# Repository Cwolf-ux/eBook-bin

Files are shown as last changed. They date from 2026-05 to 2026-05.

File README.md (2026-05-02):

# eBook-bin
这是一个基于esp32的电子书可以用来阅读小说和察看天气目前我还没有添加太多功能后续我还打算给它加上连接蓝牙耳机听音乐的功能（也许吧）
总之目前可以使用就对了（因为我是高中生所以可能没什么时间更新代码请见谅）B站：Cwolf
时钟芯片使用DS1302
屏幕的话使用的时1.54寸的黑白双色屏 如果你的屏幕是arduino中的GxEPD2_54_T8驱动也可以直接使用，24p的接口
购买链接
【闲鱼】https://m.tb.cn/h.iEBmmNw?tk=L2Xv5OOD1jG CA381 「快来捡漏【全新1.54寸 WFT0154CZ17 黑白墨水屏】」
#小程序://闲鱼/UHppd5wqVrUnHnr
点击链接直接打开

5e49f3b043350d6cdf3bbe58eff1679a
1a4ab55a5c0fa75fe380342cb2c60797
3bd9f81abdd300e44c9b036ef0b76970
18b52c07360b9da5afa7ad33fd001fbd
电路板就暂时不开源了如有需要请联系我，请各位谅解！！！

接线
========================================
 ESP32 电子书硬件接线图 (依据代码引脚)
========================================

一、墨水屏 (GxEPD2_154_T8)
--------------------------------------
ESP32引脚    墨水屏引脚
GPIO5   ->   CS
GPIO21  ->   DC
GPIO15  ->   RST
GPIO16  ->   BUSY
GPIO18  ->   SCK  (SPI时钟)
GPIO23  ->   MOSI (SPI数据输出)
3.3V    ->   VCC
GND     ->   GND

二、SD卡模块 (SPI模式)
--------------------------------------
ESP32引脚    SD卡模块引脚
GPIO4   ->   CS
GPIO18  ->   SCK   (与墨水屏共用)
GPIO19  ->   MISO
GPIO23  ->   MOSI  (与墨水屏共用)
3.3V    ->   VCC
GND     ->   GND

三、DS1302 实时时钟
--------------------------------------
ESP32引脚    DS1302引脚
GPIO14  ->   DAT (I/O)
GPIO27  ->   CLK (SCLK)
GPIO12  ->   RST (CE)
3.3V    ->   VCC
GND     ->   GND

四、按钮 (内部上拉，按下为低电平)
--------------------------------------
左键: GPIO26 --[按键]-- GND
中键: GPIO32 --[按键]-- GND
右键: GPIO33 --[按键]-- GND

五、LED背光
--------------------------------------
GPIO25 --[220欧电阻]-- LED阳极 -- LED阴极 -- GND

六、电池电压测量 (两电阻分压)
--------------------------------------
电池正极 (+)
   │
   ├── 10kΩ电阻 ──┬── GPIO35 (ADC)
   │               │
   └── 电池负极 ── 10kΩ电阻 ── GND

说明：两个10kΩ电阻串联，中点接GPIO35。
满电4.2V时，ADC引脚电压为2.1V，安全。

七、电源连接
--------------------------------------
所有模块的VCC接ESP32的3.3V输出。
所有GND共地。
电池通过分压电路测量，ESP32主供电建议使用稳定3.3V电源。

========================================
        注意事项
========================================
1. SPI总线(18/19/23)为ESP32默认VSPI，墨水屏与SD卡仅CS不同。
2. 按钮使用内部上拉(INPUT_PULLUP)，外部无需上拉电阻。
3. 电池分压电阻已固定，软件已做校准。
4. GPIO35仅能做输入，适合ADC测量。
5. 如开发板引脚定义不同，请根据实际型号调整。

========================================
制作：Cwolf-Cc
版本：1.0
========================================

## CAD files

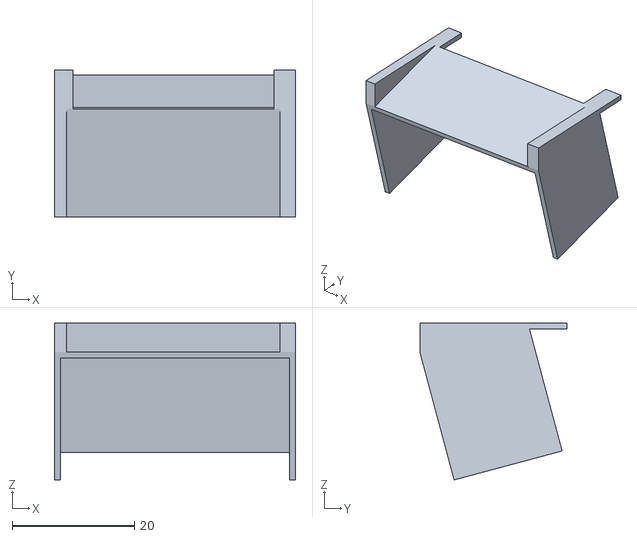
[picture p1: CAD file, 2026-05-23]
3d模型 3dmode/电子书二代支架.stl
39.5 x 24.2 x 25.7

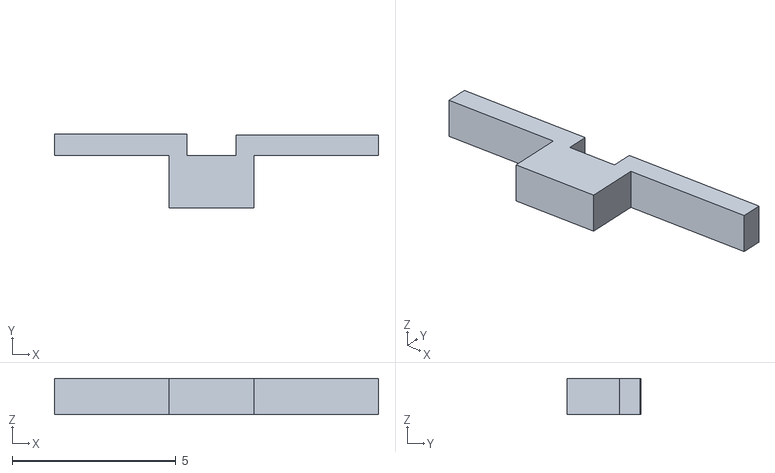
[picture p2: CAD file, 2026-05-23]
3d模型 3dmode/电子书二代开关.stl
9.90 x 2.26 x 1.10

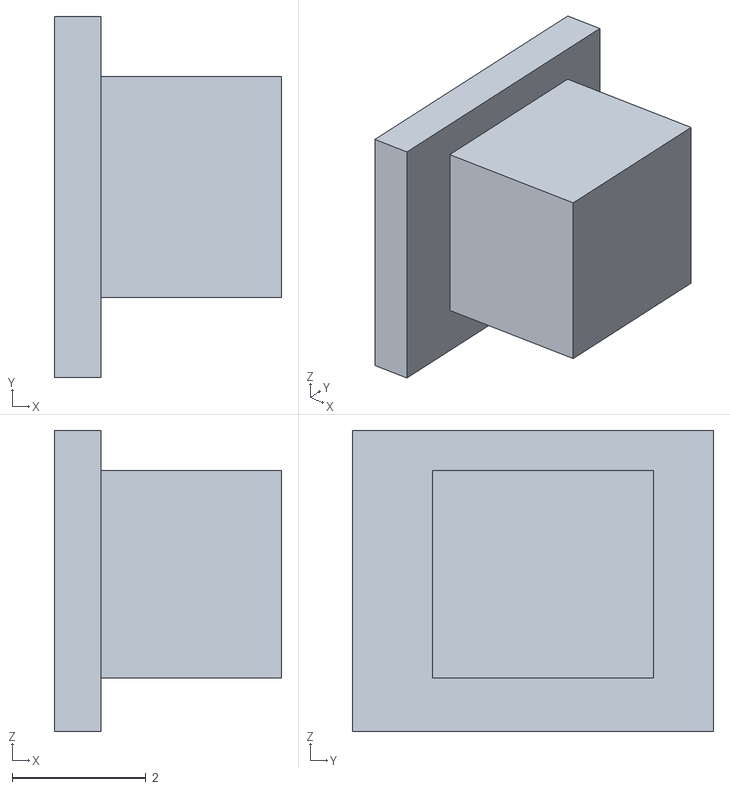
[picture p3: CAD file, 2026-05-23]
3d模型 3dmode/电子书二代按钮.stl
3.40 x 5.40 x 4.50

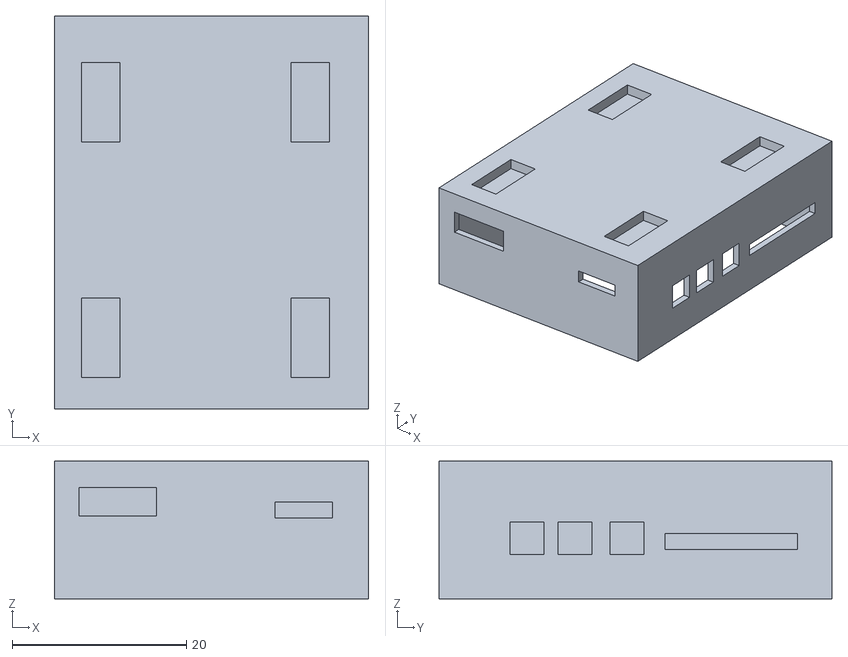
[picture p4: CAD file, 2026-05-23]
3d模型 3dmode/电子书二代主体.stl
36.0 x 45.0 x 15.8

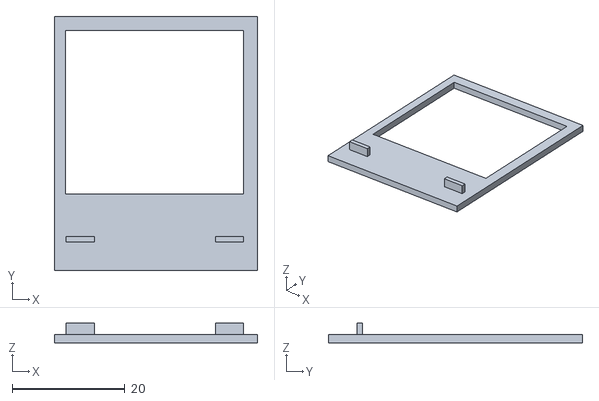
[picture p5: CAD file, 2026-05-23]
3d模型 3dmode/电子书二代顶盖.stl
36.0 x 45.0 x 3.50

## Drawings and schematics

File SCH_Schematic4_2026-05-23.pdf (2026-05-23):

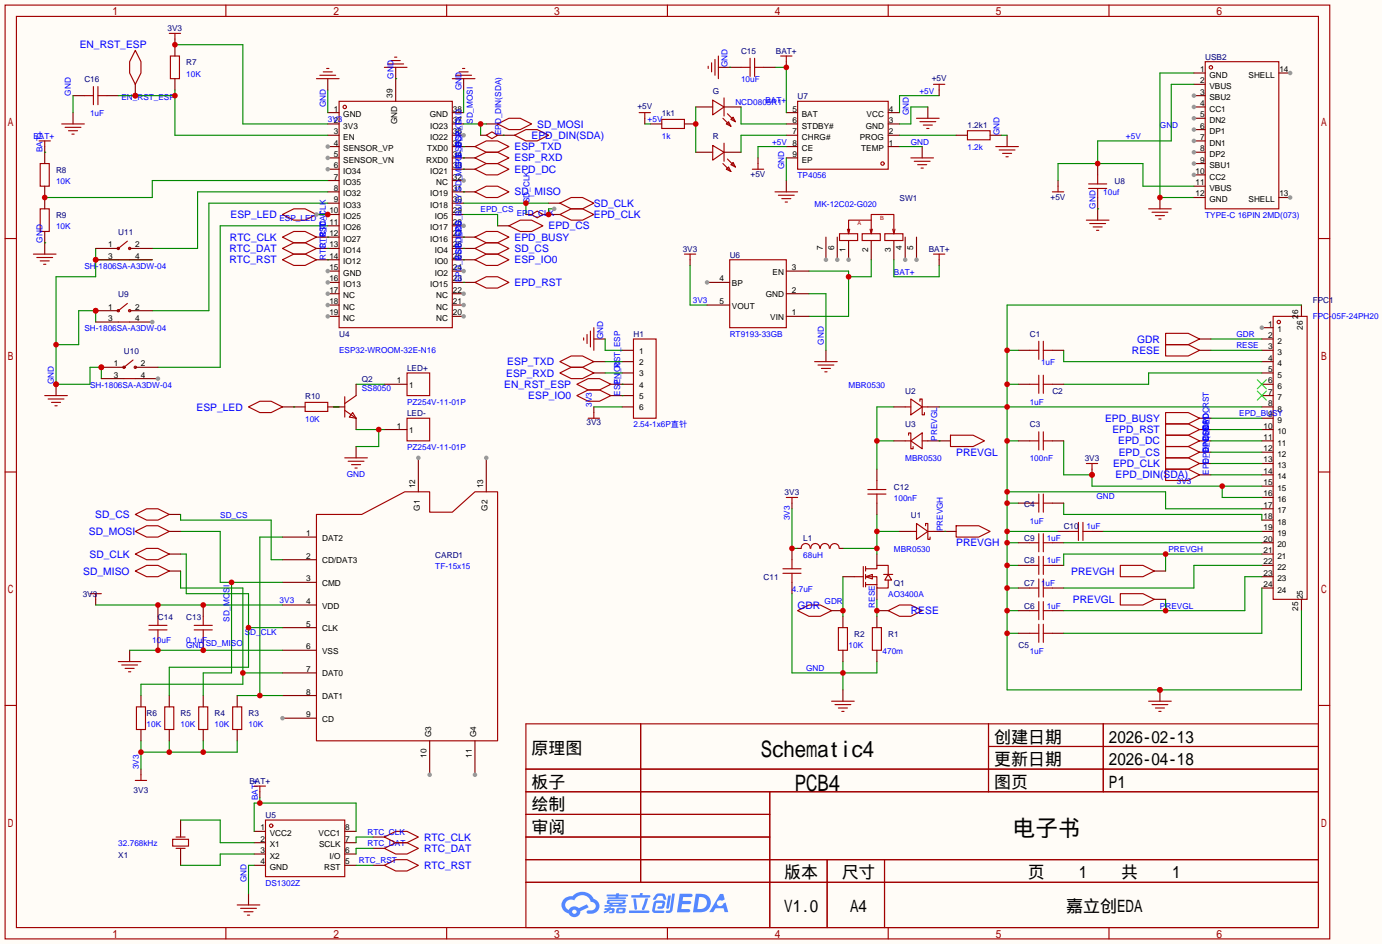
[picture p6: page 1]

原理图 | Schematic4 | 创建日期 | 2026-02-13

更新日期 | 2026-04-18

板子 | PCB4 | 图页 | P1
绘制 | | 电子书
审阅

V1.0 | A4 | 嘉立创EDA

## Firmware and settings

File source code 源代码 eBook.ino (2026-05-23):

#include <GxEPD2_BW.h>
#include <U8g2_for_Adafruit_GFX.h>
#include <HTTPClient.h>
#include <stdlib.h>
#include <SPI.h>
#include <stdint.h>
#include <ThreeWire.h>
#include <RtcDS1302.h>
#include <TimeLib.h>
#include <NtpClientLib.h>
#include <ESP8266_Seniverse.h>
#include <OneButton.h>

//当升级开始时，打印日志
void update_started() {

}
//当升级结束时，打印日志
void update_finished() {

}
//当升级中，打印日志
void update_progress(int cur, int total) {

}
//当升级失败时，打印日志
void update_error(int err) {
  Serial.printf("CALLBACK:  HTTP update fatal error code %d\n", err);
 }

#include <HTTPUpdate.h>
#include <SimpleTimer.h>

const String BINID = "1.0";
volatile int BT;
char* VERSION_URL;
volatile int WZ;
volatile bool SDcard;
volatile int page;
volatile int Mode;
volatile int chooes;
volatile int ZT;
volatile int i;
volatile int P;
volatile long K;
String RWB;
volatile int TQGX;
volatile int CSX;
volatile int SX;
volatile int LED;
String Bin;
String cmd;
ThreeWire Wire_14_27_12(14, 27, 12);
RtcDS1302<ThreeWire> rtc(Wire_14_27_12);
String TQ[]={"N/A", "N/A", "N/A", "N/A", "N/A", "N/A", "N/A", "N/A", "N/A", "N/A", "N/A", "N/A", "N/A", "N/A", "N/A"};

int8_t timeZone = 8;
const PROGMEM char *ntpServer = "ntp1.aliyun.com";
Forecast forecast;
WeatherNow weatherNow;
String WB[]={"System", "N/A", "N/A", "N/A", "N/A", "N/A", "N/A", "N/A"};

OneButton button33(33, true);
OneButton button26(26, true);
OneButton button32(32, true);
SimpleTimer timer;

//墨水屏初始化
GxEPD2_BW<GxEPD2_154_T8, GxEPD2_154_T8::HEIGHT> display(GxEPD2_154_T8(5, 21, 15, 16));
U8G2_FOR_ADAFRUIT_GFX u8g2;

#include <WiFiManager.h>
  WiFiManager wm;
  bool res;
#include <SdFat.h>
#include <string.h>
extern SdFs sd;
SdFat SD;
SdFat sd;
SdFile myFile;
void attachDoubleClick33() {
  if (ZT == 1) {
    ZT = 2;

  }
  SX = 0;

}

void attachLongPressStart26() {
  if (page == 1) {
    page++;

  }
  SX = 0;

  clearEPD();
}

void attachLongPressStart32() {
  if (page == 2 && Mode == 0) {
    page--;

  }
  if (ZT >= 1) {
    Mode = 1;

  } else {
    Mode = 0;

  }
  if (ZT >= 1) {
    //设置中文字体字号15
    u8g2.setFont(u8g2_font_wqy12_t_gb2312);
    display.fillRoundRect(25, 45, 95, 52, 5, GxEPD_WHITE);
    display.drawRoundRect(30, 50, 90, 50, 5, GxEPD_BLACK);
    showCH(50, 70, "保存中...");
    JSX(0, 0, 255, 255);
    (createFileWithContent("Save", Sou(chooes), K));
    ZT = 0;

  }
  chooes = 1;
  SX = 0;
  clearEPD();
 
}

void attachDuringLongPress33() {
  if (ZT == 2 && K > 50) {
    K = K - 100;

  }
  if (Bin != " " && (Mode == 4 && chooes == 2)) {
    if (Bin == BINID) {
      //设置中文字体字号15
      u8g2.setFont(u8g2_font_wqy12_t_gb2312);
      display.fillRoundRect(25, 45, 95, 52, 5, GxEPD_WHITE);
      display.drawRoundRect(30, 50, 90, 50, 5, GxEPD_BLACK);
      showCH(50, 70, "开始更新");
      showCH(40, 85, "大概需要2~3分钟");
      JSX(0, 0, 255, 255);
      WiFiClient OTAUpdateClient;
 
      httpUpdate.onStart(update_started);//当升级开始时
      httpUpdate.onEnd(update_finished); //当升级结束时
      httpUpdate.onProgress(update_progress); //当升级中
      httpUpdate.onError(update_error); //当升级失败时
      t_httpUpdate_return ret = httpUpdate.update(OTAUpdateClient, "http://bin.bemfa.com/b/314612/3BcMGEyM2QyNzliZGI1NGYyYzgyNDdjNTZlMzRmYzZiZTY=eBook.bin");
      switch(ret) {
        case HTTP_UPDATE_FAILED:      //当升级失败
      
          break;
        case HTTP_UPDATE_NO_UPDATES:  //当无升级
     
          break;
        case HTTP_UPDATE_OK:         //当升级成功

          break;
        }

    }

  }
  SX = 0;
 
}

void attachClick26() {
  if (((page == 2 && chooes < 5) && Mode == 0) && ZT == 0) {
    chooes++;

  }
  if (Mode == 1 && ZT == 0) {
    chooes++;
    i = 1;
    P = 0;

  }
  if (Mode == 4) {
    chooes++;

  }
  if (ZT == 1) {
    K = K + 1;

  }
  if (ZT == 2) {
    K = K + 10;

  }
  clearEPD();
  SX = 0;

}

void Simple_timer_1() {
  if (page == 1) {
    SX = 0;
    clearEPD();

  }
}

void Simple_timer_2() {
  TQGX = 0;
}

void attachDuringLongPress26() {
  if (ZT == 2) {
    K = K + 50;

  }
  clearEPD();
  SX = 0;
}

void attachClick32() {
  if ((page == 2 && chooes > 1) && Mode == 0) {
    chooes--;

  }
  if (Mode == 1 && ZT == 0) {
    chooes--;
    i = 1;
    P = 0;

  }
  if (Mode == 4) {
    chooes--;

  }
  if (ZT == 1) {
    K = K - 1;

  }
  clearEPD();
  SX = 0;

}

void attachClick33() {
  if (Mode == 1 && ZT == 0) {
    ZT = 1;
    //设置中文字体字号15
    u8g2.setFont(u8g2_font_wqy12_t_gb2312);
    display.fillRoundRect(25, 25, 95, 72, 5, GxEPD_WHITE);
    display.drawRoundRect(30, 30, 90, 70, 5, GxEPD_BLACK);
    showCH(50, 45, "读取中...");
    showCH(32, 65, "首次耗时较长");
    showCH(32, 85, "可能要5~6分钟");
    JSX(0, 0, 255, 255);
    K = RadeSave("Save", Sou(chooes));

  }
  if (page == 2 && Mode == 0) {
    Mode = chooes;
    if (Mode == 4) {
      chooes = 1;

    }

  }
  if (ZT == 2 && K > 10) {
    K = K - 50;

  }
  i = 1;
  P = 0;
  clearEPD();
  SX = 0;

  if (page == 2 && Mode == 0) {
    Mode = chooes;
    if (Mode == 4) {
      chooes = 1;

    }

  }
  if (Mode == 4) {
    if (chooes == 2) {
      display.fillRoundRect(15, 45, 105, 90, 5, GxEPD_WHITE);
      display.drawRoundRect(16, 50, 105, 88, 5, GxEPD_BLACK);
      // wifi的状态
      if (WiFi.status() == 3) {
        showCH(20, 70, "正在获取最新版本...");
        showCH(20, 90, "可长按返回中断");
        JSX(0, 0, 255, 255);
        Bin = "";
        while (Bin == "") {
          Bin = getServerVersion();
          delay(1500);
          if (digitalRead(26) == 0) {
            Bin = "获取失败";

          }
   
        }
        if (Bin != "获取失败") {
          display.fillRoundRect(15, 45, 105, 52, 5, GxEPD_WHITE);
          display.drawRoundRect(20, 50, 100, 50, 5, GxEPD_BLACK);
          showCH(30, 70, "获取成功");
          JSX(0, 0, 255, 255);
          delay(600);

        }

      } else {
        showCH(40, 70, "网络未连接");

      }

    }
    if (chooes == 3) {
      //设置中文字体字号15
      u8g2.setFont(u8g2_font_wqy12_t_gb2312);
      display.fillRoundRect(25, 45, 95, 52, 5, GxEPD_WHITE);
      display.drawRoundRect(30, 50, 90, 50, 5, GxEPD_BLACK);
      // wifi的状态
      if (WiFi.status() == 3) {
        while (NTP.getDateYear() == 1970) {
          delay(500);
        }
        //设置中文字体字号12
        u8g2.setFont(u8g2_font_wqy12_t_gb2312);
        rtc.SetDateTime(RtcDateTime(NTP.getDateYear(), NTP.getDateMonth(), NTP.getDateDay(), NTP.getTimeHour24(), NTP.getTimeMinute(), NTP.getTimeSecond()));
        while (rtc.GetDateTime().Minute() != NTP.getTimeMinute()) {
          delay(100);
        }
        showCH(50, 65, "校准成功");

      } else {
        showCH(50, 65, "网络未连接");

      }
      JSX(0, 0, 255, 255);

    }

  }
  if (ZT == 2 && K > 10) {
    K = K - 50;

  }
  i = 1;
  P = 0;
  clearEPD();
  SX = 0;
 
}

char* changetxt(String str) {
  return const_cast<char*>(str.c_str());
}

void clearEPD() {
  display.fillScreen(GxEPD_WHITE); // 填充白色
}

void QSX() {
  display.display(false);
}

void attachDoubleClick26() {
  if (LED == 1) {
    dacWrite(25, 0);
    LED = 0;

  } else {
    dacWrite(25, 255);
    LED = 1;

  }
  //设置中文字体字号15
  u8g2.setFont(u8g2_font_wqy12_t_gb2312);
  display.fillRoundRect(25, 45, 95, 52, 5, GxEPD_WHITE);
  display.drawRoundRect(30, 50, 90, 50, 5, GxEPD_BLACK);
  if (LED == 1) {
    showCH(50, 70, "灯已开启");

  } else {
    showCH(50, 70, "灯已关闭");

  }
  JSX(0, 0, 255, 255);
  delay(500);
  clearEPD();
  SX = 0;
}

long RadeSave(char* path, char* filename) {

      String fullPath = String(path) + "/" + filename;

      if (myFile.open(fullPath.c_str(), O_READ)) {
          String numberStr = "";
          while (myFile.available()) {
              char c = myFile.read();
              if (isDigit(c) || c == '-') {
                  numberStr += c;
              }
          }
          myFile.close();

          if (numberStr.length() > 0) {
              int value = numberStr.toInt();
       
              return value;
          }
      }


      return 0;

}

bool createFileWithContent(char* path, char* filename, int value) {
   {
      // 构建完整文件路径
      String fullPath = String(path);
      if (!fullPath.endsWith("/")) {
          fullPath += "/";
      }
      fullPath += filename;

      // 先创建目录（如果不存在）
      if (!sd.exists(path)) {
          if (!sd.mkdir(path)) {
              Serial.print("Failed to create directory: ");
            
              return false;
          }
          Serial.print("Directory created: ");

      }

      // 在指定路径创建文件并写入整数
      if (myFile.open(fullPath.c_str(), O_RDWR | O_CREAT | O_TRUNC)) {
          myFile.println(value);
          myFile.close();
          Serial.print("File created with value: ");
          Serial.print(fullPath);
          Serial.print(" -> ");

          return true;
      } else {
   
          return false;
      }
  }
}

void Mode0() {
  if (Mode == 0) {
    if (page == 1) {
      if (TQGX == 0 && (weatherNow.update() && forecast.update())) {
        TQ[0] = weatherNow.getWeatherText();
        TQ[1] = weatherNow.getDegree();
        TQ[2] = forecast.getHigh(0);
        TQ[3] = forecast.getLow(0);
        TQ[4] = forecast.getRain(0);
        TQ[5] = forecast.getHumidity(0);
        TQ[6] = forecast.getWindDirection(0);
        TQ[7] = forecast.getWindSpeed(0);
        TQ[8] = forecast.getWindScale(0);
        TQGX = 1;

      }
      u8g2.setFont(u8g2_font_timR24_tf);
      showCH(10, 30, changetxt(String(rtc.GetDateTime().Hour()) + String(":") + String(rtc.GetDateTime().Minute())));
      //设置中文字体字号15
      u8g2.setFont(u8g2_font_wqy15_t_gb2312);
      showCH(92, 15, changetxt(String(rtc.GetDateTime().Month()) + String("月") + String(rtc.GetDateTime().Day()) + String("日")));
      switch (rtc.GetDateTime().DayOfWeek()) {
       case 0:
        showCH(95, 32, changetxt("星期天"));
        break;
       case 1:
        showCH(95, 32, changetxt("星期一"));
        break;
       case 2:
        showCH(95, 32, changetxt("星期二"));
        break;
       case 3:
        showCH(95, 32, changetxt("星期三"));
        break;
       case 4:
        showCH(95, 32, changetxt("星期四"));
        break;
       case 5:
        showCH(95, 32, changetxt("星期五"));
        break;
       case 6:
        showCH(95, 32, changetxt("星期六"));
        break;
      }
      display.drawRect(0, 0, 150, 35, GxEPD_BLACK);
      display.drawFastVLine(90, 0, 34, GxEPD_BLACK);
      //设置中文字体字号15
      u8g2.setFont(u8g2_font_wqy12_t_gb2312);
      if (BT == 2) {
         u8g2.setFont(u8g2_font_open_iconic_all_1x_t);
          u8g2.drawGlyph(130,50+1*8,94);

      }
      showCH(2, 50, changetxt(String("当前天气：") + String(TQ[0])));
      showCH(2, 65, changetxt(String("当前温度：") + String(TQ[1]) + String("℃")));
      showCH(50, 135, changetxt(String("剩余电量：") + String(getBatteryPercent()) + String("%")));
      //设置中文字体字号12
      u8g2.setFont(u8g2_font_wqy12_t_gb2312);
      showCH(0, 80, changetxt(String("降水概率：") + String(TQ[4]) + String("%")));
      showCH(0, 95, changetxt(String("湿度：") + String(TQ[5]) + String("%")));
      showCH(0, 110, changetxt(String("↑") + String(TQ[2]) + String("℃") + String("↓") + String(TQ[3]) + String("℃")));
      // wifi的状态
      if (WiFi.status() == 3) {
          u8g2.setFont(u8g2_font_open_iconic_all_2x_t);
          u8g2.drawGlyph(5,133+1*8,248);

      }
      if (SDcard == 1) {
          u8g2.setFont(u8g2_font_open_iconic_all_2x_t);
          u8g2.drawGlyph(30,133+1*8,167);

      }
      display.drawFastHLine(90, 17, 60, GxEPD_BLACK);
      display.drawFastHLine(0, 115, 150, GxEPD_BLACK);

    }
    if (page == 2) {
      //设置中文字体字号15
      u8g2.setFont(u8g2_font_wqy12_t_gb2312);
      showCH(5, 40, "阅读");
      showCH(65, 40, "天气");
      showCH(126, 40, "配网");
      showCH(126, 100, "设置");
        u8g2.setFont(u8g2_font_open_iconic_all_2x_t);
        u8g2.drawGlyph(10,5+2*8,97);
      //阅读图标
        u8g2.setFont(u8g2_font_open_iconic_all_2x_t);
        u8g2.drawGlyph(70,5+2*8,127);
      //天气图标
      u8g2.setFont(u8g2_font_open_iconic_all_2x_t);
        u8g2.drawGlyph(130,5+2*8,102);
      //配网图标
        u8g2.setFont(u8g2_font_open_iconic_all_2x_t);
        u8g2.drawGlyph(130,65+2*8,129);

      switch (chooes) {
       case 1:
        display.drawRoundRect(0, 2, 40, 42, 5, GxEPD_BLACK);
        break;
       case 2:
        display.drawRoundRect(57, 2, 40, 42, 5, GxEPD_BLACK);
        break;
       case 3:
        display.drawRoundRect(120, 2, 32, 42, 5, GxEPD_BLACK);
        break;
       case 4:
        display.drawRoundRect(120, 62, 32, 42, 5, GxEPD_BLACK);
        break;
      }

    }

  }
}

void showCH(int x, int y, char* contest) {
  u8g2.drawUTF8(x, y,contest);
}

String cuttxt(String contest, int a, int b) {

    if (a < 1 || b < a || contest.length() == 0) {
      return "";
    }

    const char* str = contest.c_str();
    int len = contest.length();
    int charCount = 0;
    int startPos = -1;
    int endPos = len;

    // 扫描UTF-8字符串找到起始和结束位置
    for (int i = 0; i < len; i++) {
      uint8_t byte = (uint8_t)str[i];

      // 检测UTF-8字符开始
      bool isCharStart = false;
      if (byte < 0x80) {
        // ASCII字符 (0xxxxxxx)
        isCharStart = true;
      } else if ((byte & 0xE0) == 0xC0) {
        // 2字节UTF-8开始 (110xxxxx)
        isCharStart = true;
      } else if ((byte & 0xF0) == 0xE0) {
        // 3字节UTF-8开始 (1110xxxx) - 中文字符
        isCharStart = true;
      } else if ((byte & 0xF8) == 0xF0) {
        // 4字节UTF-8开始 (11110xxx)
        isCharStart = true;
      }
      // 续字节 (10xxxxxx) 不计数

      if (isCharStart) {
        charCount++;

        // 标记起始位置
        if (charCount == a && startPos == -1) {
          startPos = i;
        }

        // 标记结束位置
        if (charCount == b + 1) {
          endPos = i;
          break;
        }
      }
    }

    // 如果没找到起始位置，返回空字符串
    if (startPos == -1) {
      return "";
    }

    // 提取子字符串
    return contest.substring(startPos, endPos);

}

void SX2() {
  if (ZT != 1) {
    if (CSX == 10) {
      QSX();
      CSX = 0;

    } else {
      JSX(0, 0, 255, 255);
      CSX++;

    }
    SX = 1;

  } else {
    if (CSX == 15) {
      QSX();
      CSX = 0;

    } else {
      JSX(0, 0, 255, 255);
      CSX++;

    }
    SX = 1;

  }
}

void JSX(int x, int y, int w, int h) {
  display.setPartialWindow(x, y, w, h);
  display.display(true);
}

String getServerVersion() {
    HTTPClient http;
    http.begin(VERSION_URL);

    int httpCode = http.GET();
    if (httpCode != HTTP_CODE_OK) {
      http.end();
      return "";
    }

    String ver = http.getString();
    http.end();
    ver.trim(); // 去掉空格、换行

    return ver;
}

char* Sou(int i) {

    static char name[256]; // 静态数组保证返回后内存有效
    name[0] = '\0'; // 初始化为空字符串

    FsFile root = sd.open("/");
    if(!root || !root.isDir()) {
      return name;
    }

    FsFile file;
    int count = 0;
    while((file = root.openNextFile())) { // 修改为直接检查文件是否有效
      if(count++ == i) {
        file.getName(name, sizeof(name));
        file.close();
        break;
      }
      file.close();
    }

    root.close();
    return name;

}

void attachDoubleClick32() {
  QSX();

}
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
void loop() {
  // 确认
  button33.tick();
  // 右键
  button26.tick();
  // 左键
  button32.tick();


  // 确认
  button33.tick();
  // 右键
  button26.tick();
  // 天气10分钟刷新一次
  timer.run();

  // 天气10分钟刷新一次
  timer.run();

  // 右键
  button26.tick();
  // 左键
  button32.tick();
  // 确认
  button33.tick();
  // 右键
  button26.tick();
  // 左键
  button32.tick();
  if (SX == 0) {
    Mode0();
    App();
    SX2();

  }
  delay(20);

}

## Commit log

2026-02-11 Add files via upload
    固件本体
2026-05-23 Rename eBook.ino to source code 源代码 eBook.ino
